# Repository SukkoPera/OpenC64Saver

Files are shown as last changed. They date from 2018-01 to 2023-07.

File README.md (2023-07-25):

## OpenC64Saver

OpenC64Saver is an Open Hardware implementation of the [Computer Saver device developed by Ray Carlsen](https://portcommodore.com/rcarlsen/cbm/c64/SAVER/saver.txt), mainly targeted at Commodore 64 users, but also usable on VIC-20 computers.

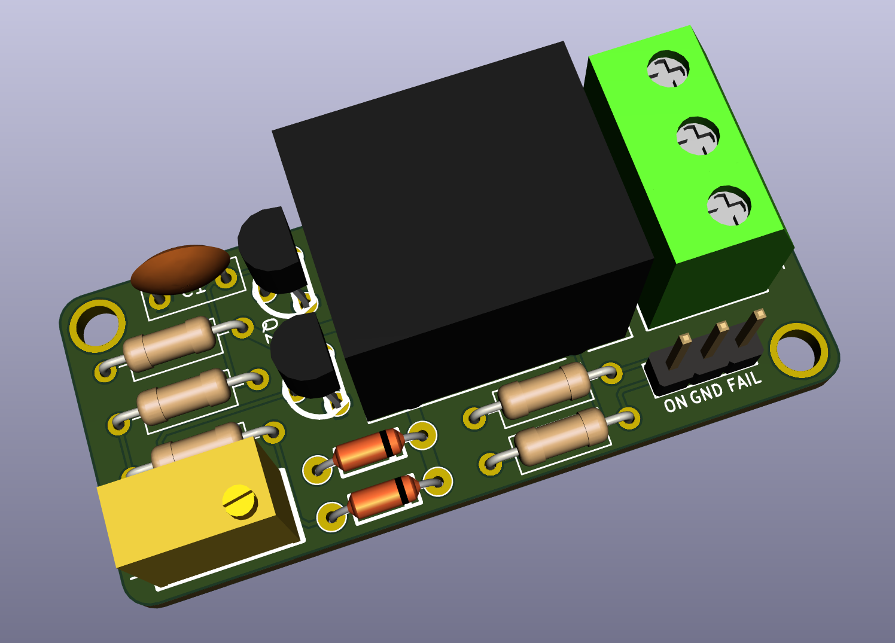
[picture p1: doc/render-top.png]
Board


### Summary
> This over-voltage protection unit is designed to prevent damage to
the Commodore 64 computer due to a failing power supply. One of the ways
the Commodore "brick" power supply can fail is from a shorted internal
5 volt regulator. That fault puts excessive voltage into the computer
and damages chips such as RAM very quickly... and silently. The Saver
protector is essentially a fast-acting electronic circuit breaker. It
functions to quickly cut off the 5 volt supply line to the computer if
the voltage exceeds about 5.4 volts. It is not a "crowbar" device but
opens the line from the supply to the computer before the voltage gets
high enough to do damage. That's the safest way to do it. After-market
power supplies, even switching types, can fail at any time. Switchers
are more reliable and much less prone to catastrophic failures but can
still cause damage to the computer if they fail. This Saver is designed
to protect any computer that uses the standard Commodore "brick" power
supply as well as any newer switch-mode PS. Computers include all
versions of the C64, the later CR version of the VIC20, and the Plus/4.
Because of its square power connector, an external Saver is possible
for the Plus/4 but its power socket would have to be changed to the
round C64 version because four pin square DIN connectors are not
available. - Ray Carlsen

### Installation

#### Internal
> There are several ways to add this protection device to your system.
One way is to install the components or a completed module inside the
computer. That way, it is protected from any supply plugged into it. If
you have more than one computer, a protector can be installed in each
one. To install the protector circuit inside a C64, it is necessary to
open the +5 volt line on the circuit board. Input and output lines of
the protector are wired to each end of the now-open circuit. If your
C64 board differs from the pictures on my site, you will have to locate
the correct area of your board to open the line and make the connections.
In all internal versions, the correct point is electrically between the
power connector and the power switch. There are at least five board
versions of that computer, each with a different PC board layout, and
the physical connections will be specific for each board.

Ray's C64 motherboard pictures can be found [here](https://portcommodore.com/rcarlsen/cbm/c64/SAVER/MOBOs/).

For the VIC-20 see [this](https://portcommodore.com/rcarlsen/cbm/vic20/VIC20CR/saver%20mod.jpg). Note that you will have to cut a trace.

#### External
You can also put your OpenC64Saver in an external box, by using one of those common small boxes for electronic stuff. If you have a 3D printer available, you can also print [this excellent case by Ruben Coolen](https://www.thingiverse.com/thing:3795541) (Thanks!!!).

The connectors you will need are called *DIN-7* (formally *DIN 45329*) and are very common and easy to find in both cable- and panel-mount versions. Please refer to [this page](https://www.c64-wiki.com/wiki/Power_Supply_Connector) for the wiring.

This way you will be able to use a single OpenC64Saver with different computers, both C64s and VIC-20s.

### Configuration
OpenC64Saver includes a trimmer to set the cut-off voltage:

> Because of fairly wide Saver component tolerances and to
accommodate the normal voltage variations of even good power supplies,
the basic Saver circuit must be "trimmed" so the voltage cuts off at
about 5.4 volts DC. If set too high, it will not protect the computer;
if too low it will trip prematurely even with a good PS. Feedback from
a few users indicated the Saver would trip when they turned their
computer off, and it remained in failsafe mode until unplugged from the
PS. Apparently some power supplies output can jump up past the failsafe
point when the load on them is suddenly removed (computer off). That's
why the trip point is set as high as it is. 5.4 volts is still under
the "absolute maximum rating" specification for the RAM chips.

To properly set the cut-out voltage you will need a variable DC supply and a voltmeter:
- Slowly increase the supply voltage until you hear the relay cut in (voltage appears on the relay output side)
- Continue advancing it until the relay cuts out again. The voltage at that instant is the trip point of the device.
- If it is too high, decrease the supply voltage until the relay cuts in again, rotate the trimmer screw, and repeat the above procedure.

> Note that the Zener diode is somewhat temperature sensitive. If very cold, the
trip point will read high, and if hot from soldering, the trip point will be low. Therefore, the mounting of the Saver components, if inside the computer, should be away from all heat producing components.

### License
OpenC64Saver is Open Hardware. If you make any modifications to the board, please contribute them back.

### Disclaimer
OpenC64Saver is provided to you 'as is' and without any express or implied warranties whatsoever with respect to its functionality, operability or use, including, without limitation, any implied warranties of merchantability, fitness for a particular purpose or infringement. We expressly disclaim any liability whatsoever for any direct, indirect, consequential, incidental or special damages, including, without limitation, lost revenues, lost profits, losses resulting from business interruption or loss of data, regardless of the form of action or legal theory under which the liability may be asserted, even if advised of the possibility or likelihood of such damages.

### Support the Project
Since the project is open you are free to get the PCBs made by your preferred manufacturer, however in case you want to support the development, you can order them from PCBWay through this link:

PCB from PCBWay (https://www.pcbway.com/project/shareproject/OpenC64Saver_V4.html)

You get my gratitude and cheap, professionally-made and good quality PCBs, I get some credit that will help with this and [other projects](https://www.pcbway.com/project/member/shareproject/?bmbid=41100). You won't even have to worry about the various PCB options, it's all pre-configured for you!

Also, if you still have to register to that site, [you can use this link](https://www.pcbway.com/setinvite.aspx?inviteid=41100) to get some bonus initial credit (and yield me some more).

Again, if you want to use another manufacturer, feel free to, don't feel obligated :). But then you can buy me a coffee if you want:

<a href='https://ko-fi.com/L3L0U18L' target='_blank'>Buy Me a Coffee at ko-fi.com</a>

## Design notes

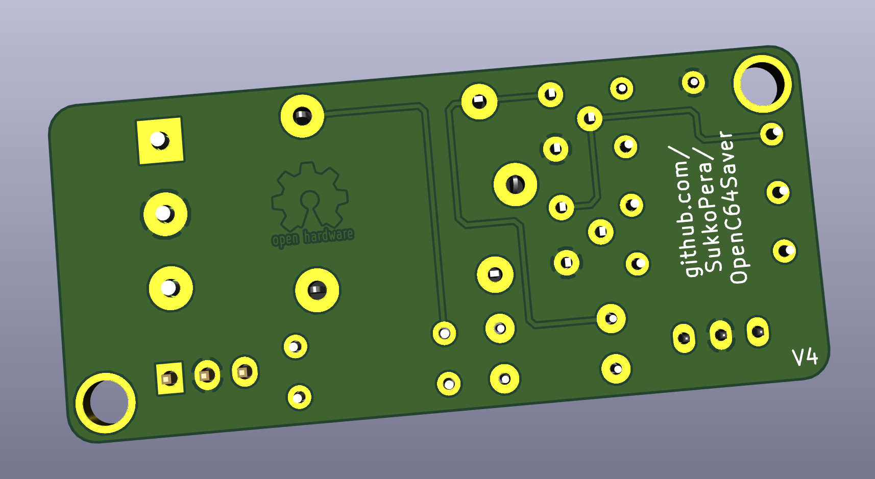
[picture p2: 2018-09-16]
doc/render-bottom.png

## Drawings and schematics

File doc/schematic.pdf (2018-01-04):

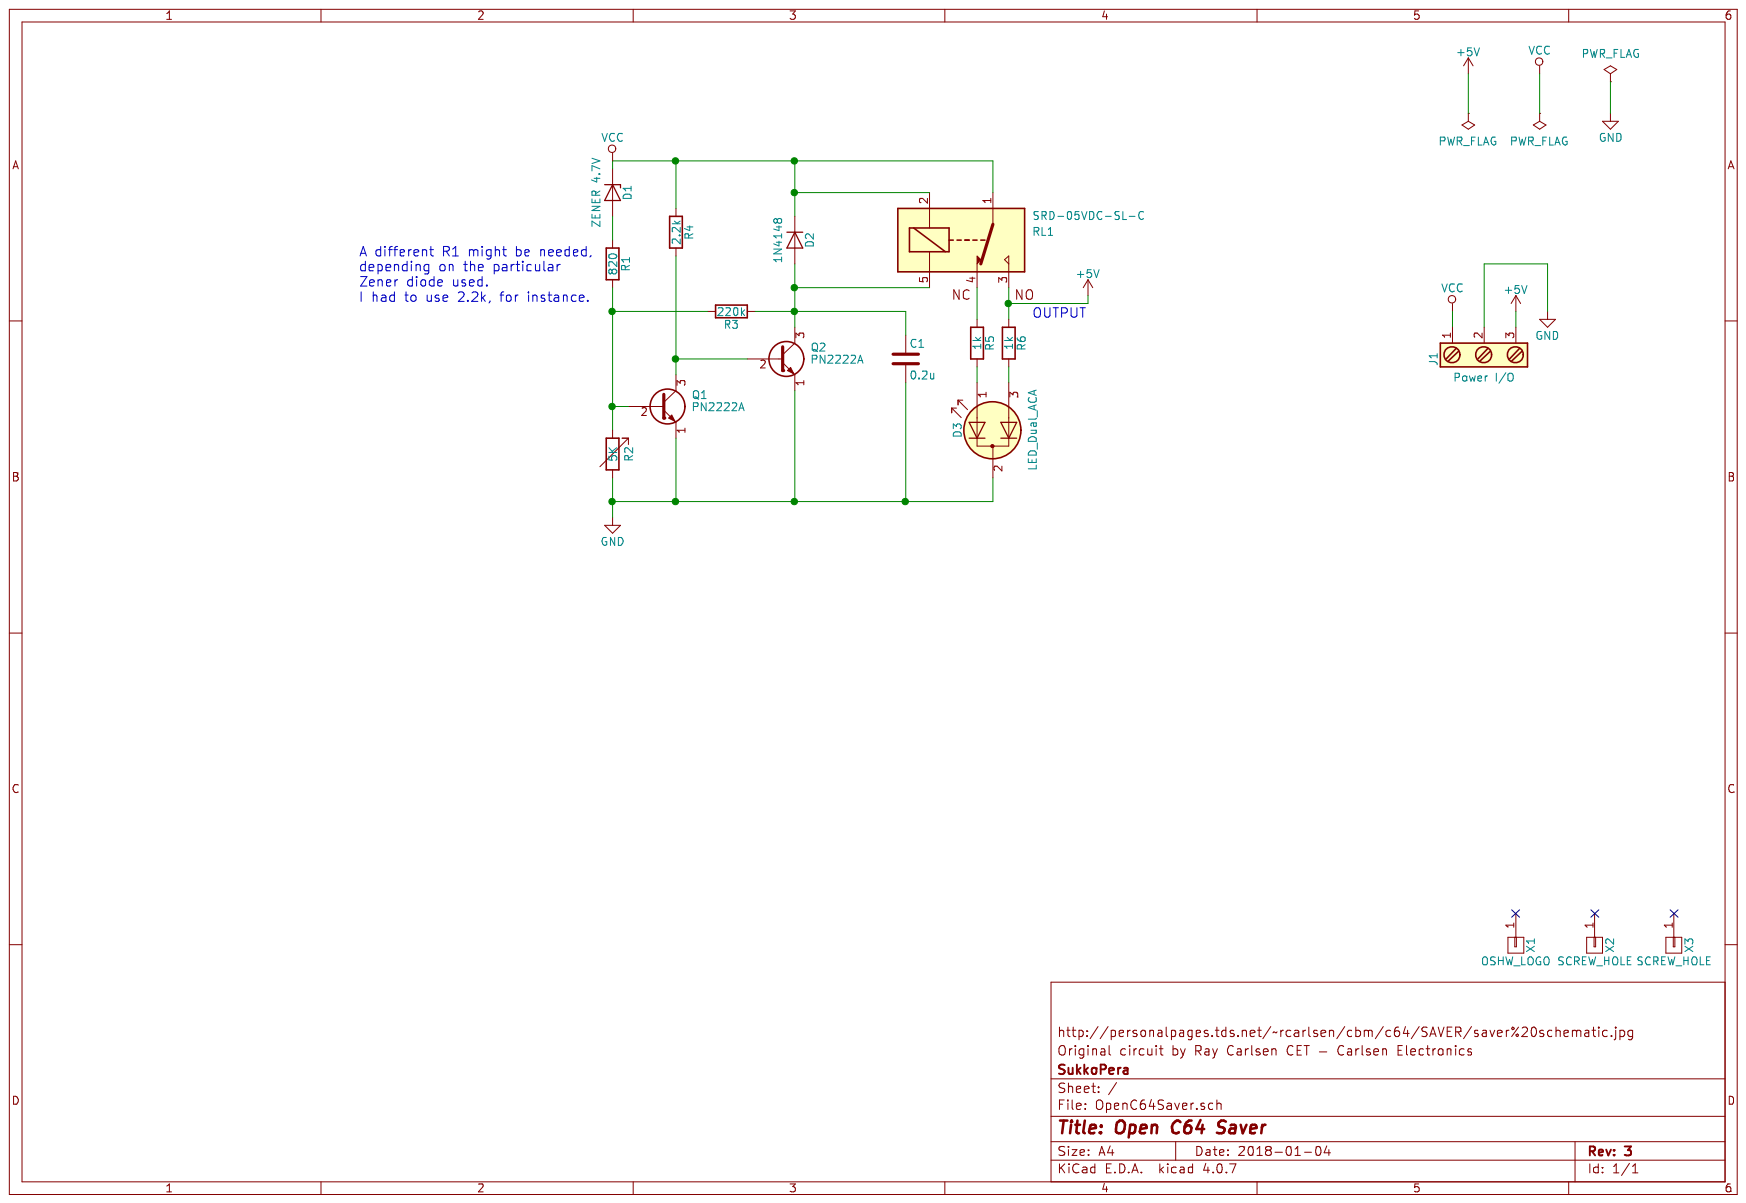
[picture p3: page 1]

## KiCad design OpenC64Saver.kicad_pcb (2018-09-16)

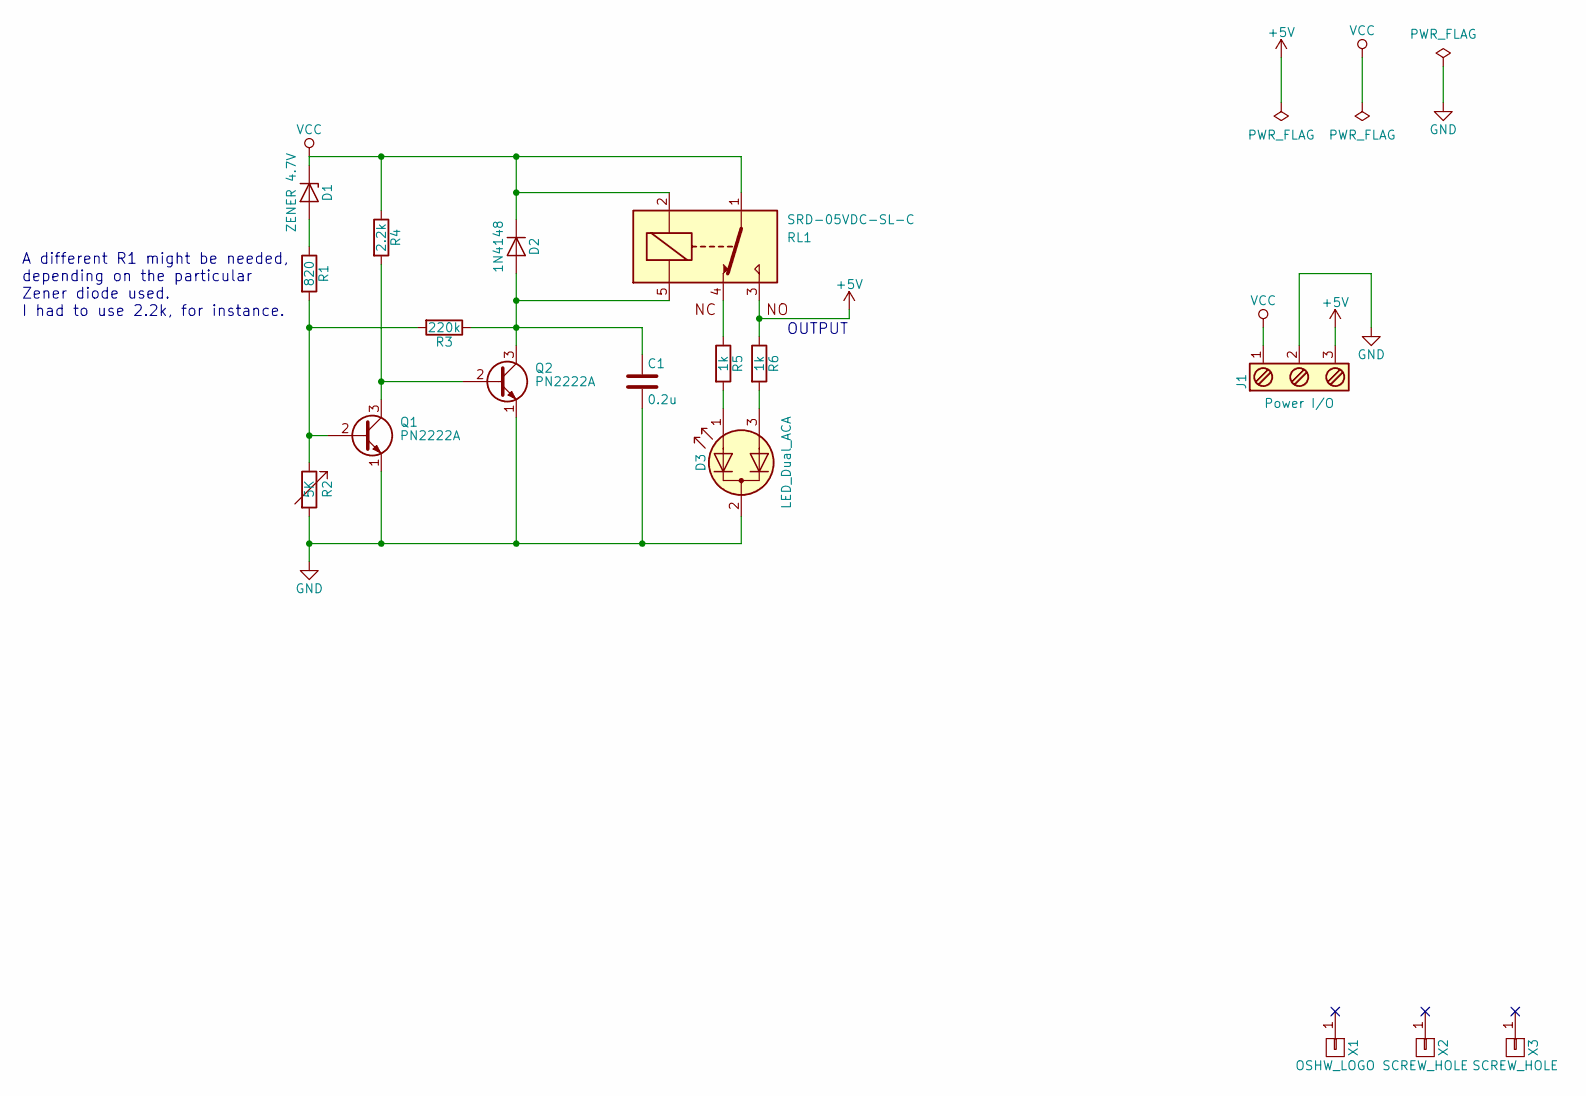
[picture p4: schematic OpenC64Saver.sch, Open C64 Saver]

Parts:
C1: 0.2u; C_Disc_D7.0mm_W2.5mm_P5.00mm
D1: ZENER 4.7V; diode_do35
D2: 1N4148; diode_do35
D3: LED_Dual_ACA; Pin_Header_Straight_1x03
J1: Power I/O; mors_3p
Q1, Q2: PN2222A; to92_ebc
R1: 820; R_Axial_DIN0207_L6.3mm_D2.5mm_P10.16mm_Horizontal
R2: 5K; trimmer_vishay_64w
R3: 220k; R_Axial_DIN0207_L6.3mm_D2.5mm_P10.16mm_Horizontal
R4: 2.2k; R_Axial_DIN0207_L6.3mm_D2.5mm_P10.16mm_Horizontal
R5, R6: 1k; R_Axial_DIN0207_L6.3mm_D2.5mm_P10.16mm_Horizontal
RL1: SRD-05VDC-SL-C; Relay_SANYOU_SRD_Series_Form_C
X1: OSHW_LOGO; Logo_copper_OSHW_6x6mm
X2, X3: SCREW_HOLE; 1pin

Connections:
+5V: J1.3, R6.1, RL1.3
GND: C1.2, D3.2 (K), J1.2, Q1.1 (E), Q2.1 (E), R2.2
unnamed: C1.1, D2.2 (A), Q2.3 (C), R3.1, RL1.5
unnamed: D1.2 (A), R1.1
unnamed: D3.1 (A1), R5.2
unnamed: D3.3 (A2), R6.2
unnamed: Q1.2 (B), R1.2, R2.1, R3.2
unnamed: Q1.3 (C), Q2.2 (B), R4.2
unnamed: R5.1, RL1.4
VCC: D1.1 (K), D2.1 (K), J1.1, R4.1, RL1.1, RL1.2

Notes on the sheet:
OUTPUT
A different R1 might be needed, depending on the particular Zener diode used. I had to use 2.2k, for instance.

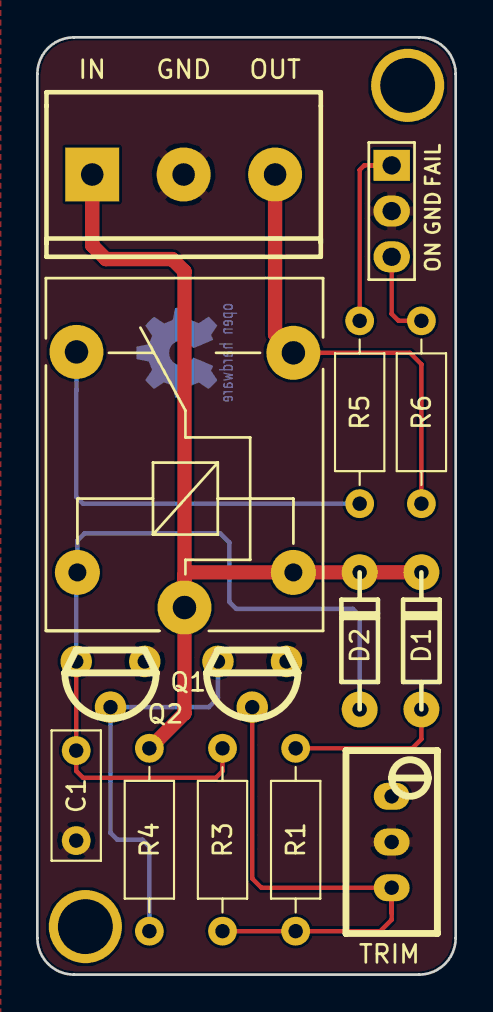
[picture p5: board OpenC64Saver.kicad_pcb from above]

Board: 2 copper layers, 23.2 x 52.1 mm, 17 parts (1 on the bottom side), 10 nets.

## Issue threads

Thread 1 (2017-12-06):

Eagle

bruktmoped, 2017-12-06:
Thanks for sharing this project!! Would it also be possible to get the filed for Eagle too? I tried to import gerber files, but it did not work.

SukkoPera, 2017-12-06:
No, I try to use only free and open source software, which Eagle is not.

Closed 2017-12-06.

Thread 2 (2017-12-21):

Panelize

bruktmoped, 2017-12-21:
Great project! Thanks! I was trying to panelize this, but the provided gerbers are not recognized by gerber panelizer. I also tried to generate gerbers again inside Kicad, but still not recognized.

SukkoPera, 2017-12-21:
Unfortunately I don't know how to do panelization at the moment. It would be good if someone took care of that and contributed panelized Gerber files.

I'm leaving this open so that it gets some visibility.

rainisto, 2018-11-06:
[C64saver_V4_Panelized.zip](https://github.com/SukkoPera/OpenC64Saver/files/2555017/C64saver_V4_Panelized.zip)

Here is panelized version that I used when I ordered a set from jlcpcb (fitted 4 boards within the normal 10x10cm limit).

SukkoPera, 2018-11-11:
Thanks Jonni, much appreciated! I will add your work to the release page.

Closed 2018-11-11.

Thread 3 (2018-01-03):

bom parts list

ogg1e, 2018-01-03:
It would be nice to have a parts list included in this design.

SukkoPera, 2018-01-04:
This is coming very soon!

SukkoPera, 2018-01-04:
Closed in V3 which was just released.

ogg1e, 2018-01-04:
a typical BOM would also include the package type for each component as well.

SukkoPera, 2018-01-04:
The BOM has the footprint, from which you can deduce the package type.

If you think a different format would be better, please provide steps for how to produce it in Kicad.

ogg1e, 2018-01-06:
I'm sorry. I didn't see the csv in the release version. I was just looking at master and I didn't see a bom.

Closed 2018-01-04.

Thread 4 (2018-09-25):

Unofficial v3 digikey bom is incorrect

MagerValp, 2018-09-25:
The unofficial v3 digikey bom unfortunately contains two errors:

C1 is a 0.2pF instead of 0.2uF (e.g. [1276-2601-1-ND](https://www.digikey.com/products/en?keywords=1276-2601-1-ND))
R1 is 0.82 Ohm instead of 820 Ohm (e.g. [A130476CT-ND](https://www.digikey.com/products/en?keywords=A130476CT-ND))

SukkoPera, 2018-09-25:
Could you please provide a fixed version?

SukkoPera, 2018-09-26:
Thanks, will update ASAP.

SukkoPera, 2018-10-09:
Updated, at last!

Closed 2018-10-09.

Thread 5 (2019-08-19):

Add Case Info

SukkoPera, 2019-08-19:
https://www.thingiverse.com/thing:3795541

By Ruben Coolen

SukkoPera, 2019-08-26:
Fixed by 2dfe76c.

Closed 2019-08-26.

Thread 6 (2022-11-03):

Question on C1 part value

dburr, 2022-11-03:
I am unable to find 0.2uf capacitors, however I do have 0.22uf ones. Can I substitute these instead, without it adversely affecting the performance?

SukkoPera, 2022-11-03:
Yes, 220nF is actually the correct common commercial value, there's no ponit in chasing down an impossible-to-find 200nF cap.

SukkoPera, 2022-11-03:
Well, reopening so that one day in the next 50 years I remember to fix this.

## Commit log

2017-09-02 Initial import
    [C64Saver.kicad_pcb, C64Saver.sch]
2017-09-02 Relabel some components
    [C64Saver.kicad_pcb, C64Saver.sch]
2017-09-02 Work in progress
    [C64Saver.kicad_pcb]
2017-09-02 Rename files to "official" project name
    [OpenC64Saver.kicad_pcb, OpenC64Saver.sch]
2017-09-02 Full board redesign to make it narrower
    [OpenC64Saver.kicad_pcb, OpenC64Saver.sch]
2017-09-30 Make board slightly larger so silkscreen doesn't get cut
    [OpenC64Saver.kicad_pcb]
2017-09-30 Tighter soldermask
    [OpenC64Saver.kicad_pcb]
2017-09-30 Bump version
    [OpenC64Saver.kicad_pcb]
2017-09-30 Even tighter soldermask
    [OpenC64Saver.kicad_pcb]
2017-10-02 Fix 3D models
    [OpenC64Saver.kicad_pcb]
2017-10-02 Smooth corners
    [OpenC64Saver.kicad_pcb]
2017-10-07 Move some traces
    [OpenC64Saver.kicad_pcb]
2017-10-07 Move version number
    [OpenC64Saver.kicad_pcb]
2017-10-07 Remove R2, decrease R1 (and add note. The variable resistor is usually enough. It was R7, it is now R2.
    [OpenC64Saver.sch]
2017-10-07 Rotate R2 to reorient silkscreen on PCB
    [OpenC64Saver.sch]
2017-10-07 Remove R2 and reorient trimmer (which is now R2)
    [OpenC64Saver.kicad_pcb, OpenC64Saver.sch]
2017-10-07 Fit a 2nd screw hole
    [OpenC64Saver.kicad_pcb, OpenC64Saver.sch]
2017-10-10 Restore images of last released board
2017-12-30 Update parts for latest Kicad
    [OpenC64Saver.kicad_pcb]
2018-01-04 Final touches for V3
    [OpenC64Saver.kicad_pcb, OpenC64Saver.sch]
2018-09-16 Experimental full through-hole version
    [OpenC64Saver.kicad_pcb, OpenC64Saver.sch]
2018-09-16 Minor fix
    [OpenC64Saver.kicad_pcb]
2018-09-16 Update PCB purchase link for V4
